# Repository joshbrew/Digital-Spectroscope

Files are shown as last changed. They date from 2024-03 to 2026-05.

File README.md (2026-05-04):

# DIY Digital Spectroscopy

This repository contains free digital spectroscopy software and 3D printable .3mf files (by Davis Fay and Bernard Markus) for an Arducam + 10deg-20deg lens digital spectroscope. Uses stock 1000 line/mm diffraction grating sheets over the lens. We also added a variant (way late, sorry) using the [same tubes](https://www.patonhawksley.com/product-page/benchtop-spectroscope) from the PySpectrometer so you can get a more lab-grade image. The slit uses single edge stainless steel razor blades glued to an adjustible front plate for precise slit width control, we achieved <0.05mm easily with a spacer.

### [Project Review Paper (draft)](https://docs.google.com/document/d/1jqOdnaSaDtLiG4n5NSiPDjHjF8f8xg1o8EnSWcibRvs/edit?usp=drive_link)

## 3D Printing:
- [3D Prints](./3D_PRINTABLE/Main%20Modules/)
- [Arducam Spectrometer Assembly Instructions pdf](./3D_PRINTABLE/Arducam%20Spectrometer%20Assembly%20Instructions.pdf)
- [Smartphone Spectrometer Assembly Instructions pdf](./3D_PRINTABLE/Smartphone%20Spectrometer%20Assembly%20Instructions.pdf)

## Additional Resources
- [Spectrometer Machine Learning Identification Demo](https://github.com/joshbrew/cameraId-wonnx-wasm)
- [Spectrometer Workbench Demo](https://camspectrometer.netlify.app)
- [Py Spectrometer by Les' Lab](https://github.com/leswright1977/PySpectrometer2) - software should work out of the box with the USB camera!
- [Original Theremino DIY Guide](https://www.theremino.com/wp-content/uploads/files/Theremino_Spectrometer_Construction_ENG.pdf)
- [DIY Hyperspectral imaging paper](https://www.mdpi.com/2313-433X/7/8/136)

We are working on a web based hyperspectral imaging tool on top of a proof of concept identification pipeline.

### Revision 2 Phone and Arducam Mounts by Davis Fay:

<table>
  <tr>
    <td>
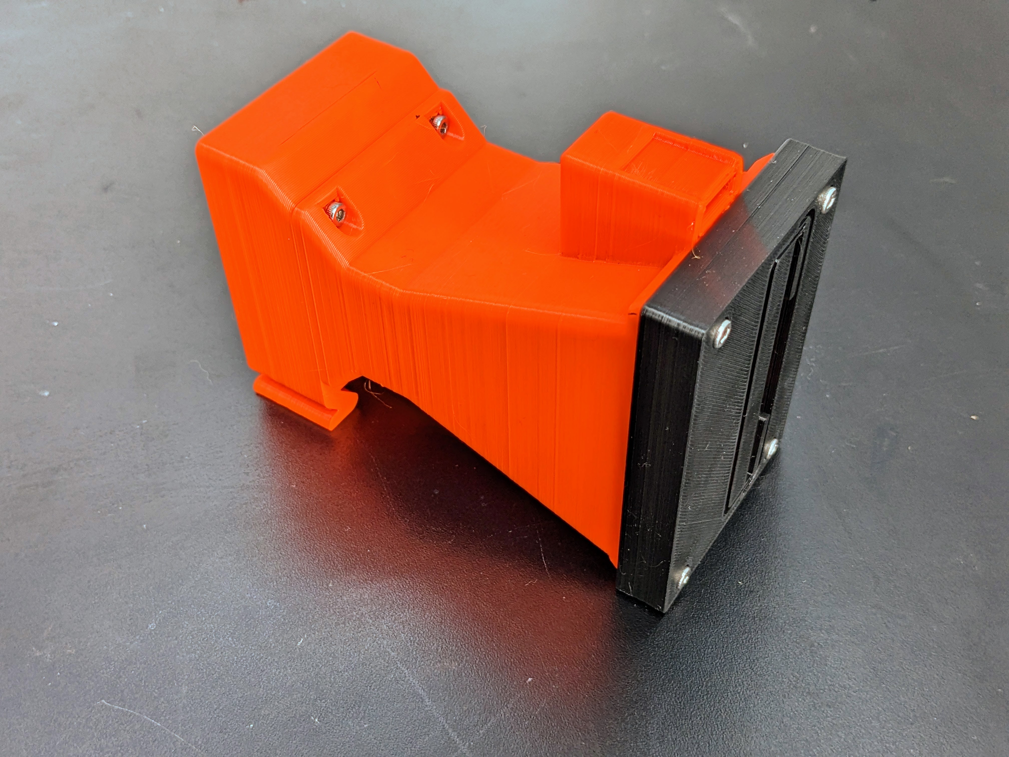
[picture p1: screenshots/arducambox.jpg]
boxa
      
    </td>
    <td>
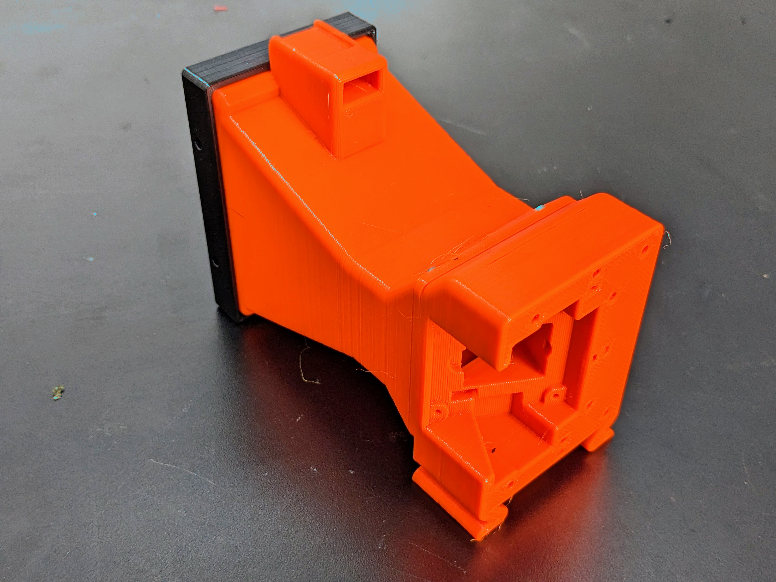
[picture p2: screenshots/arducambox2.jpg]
      
    </td>
  </tr>
  <tr>
    <td>
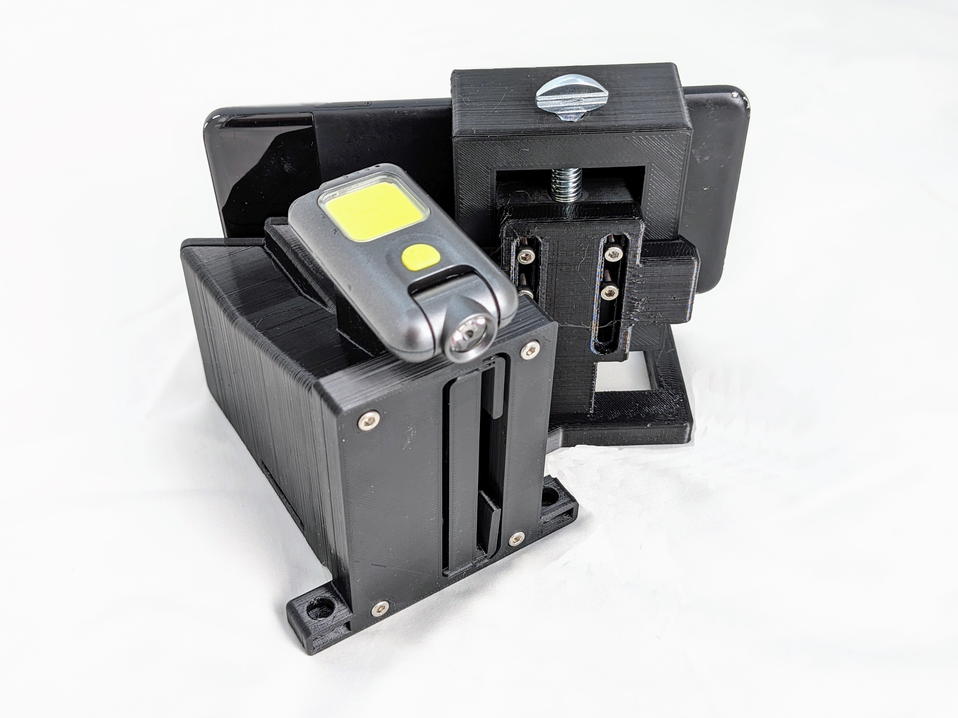
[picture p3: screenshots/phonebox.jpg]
      
    </td>
    <td>
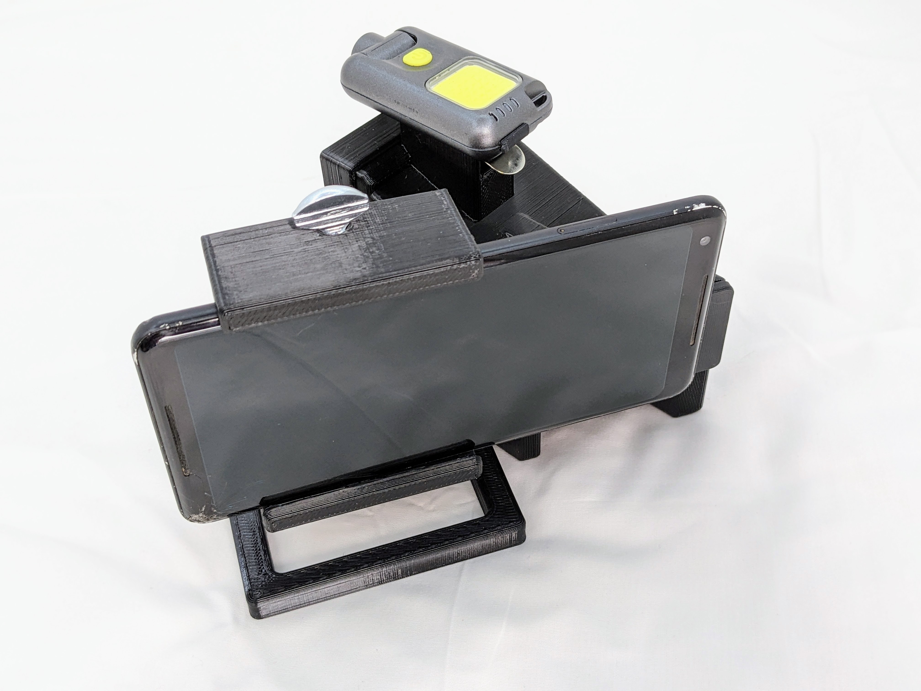
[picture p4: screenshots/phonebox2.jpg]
      
    </td>
  </tr>
</table>

### Phone Hyperspectral Imaging Results:

<table>
  <tr>
    <td>
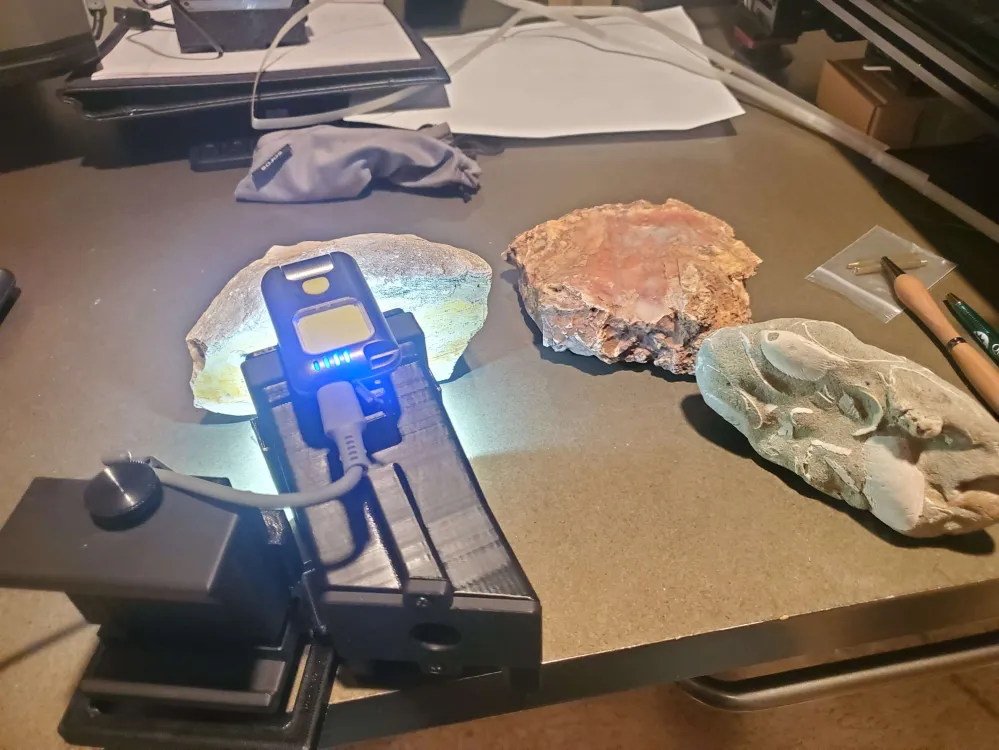
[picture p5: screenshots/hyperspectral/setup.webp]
setup
      
    </td>
    <td>
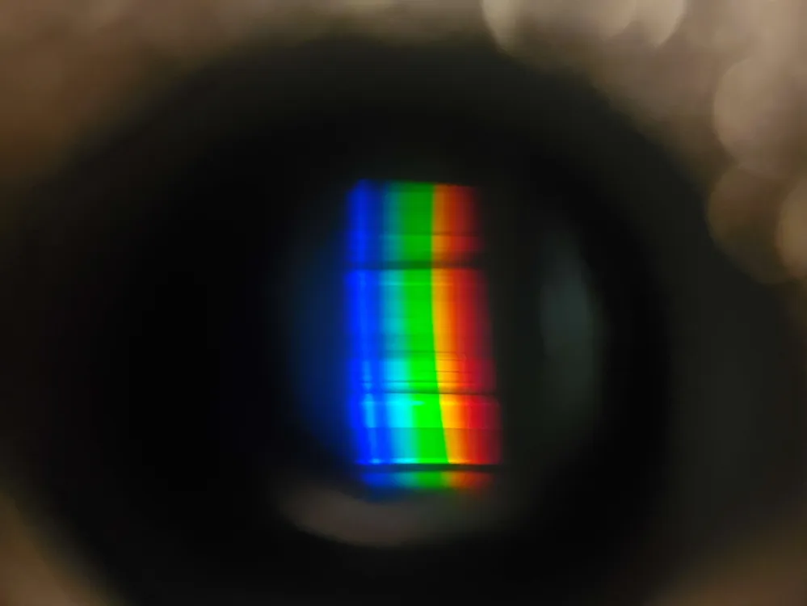
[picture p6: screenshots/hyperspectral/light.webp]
light
      
    </td>
    <td>
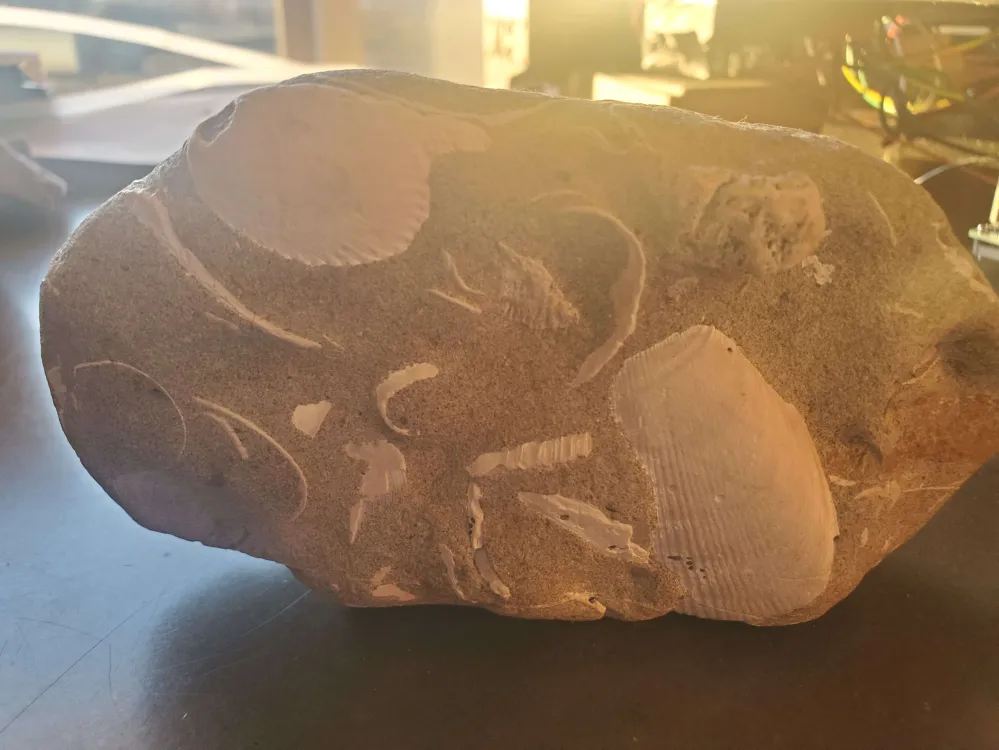
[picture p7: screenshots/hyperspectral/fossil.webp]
fossil
      
    </td>
  </tr>
  <tr>
    <td colSpan="2">
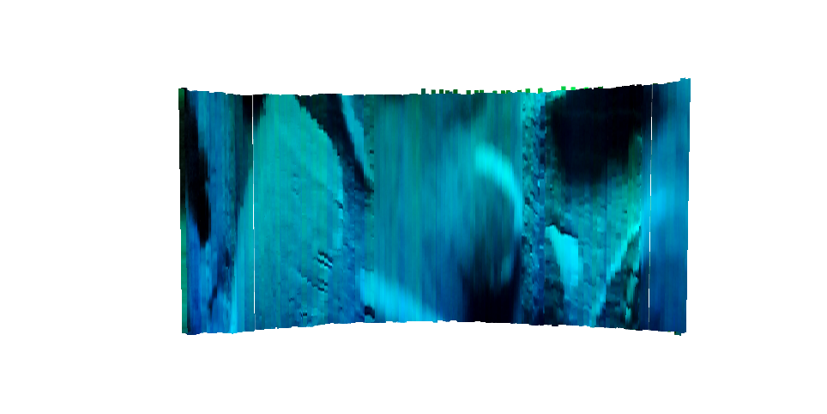
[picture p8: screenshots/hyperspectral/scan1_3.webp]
scan
      
    </td>
    <td>
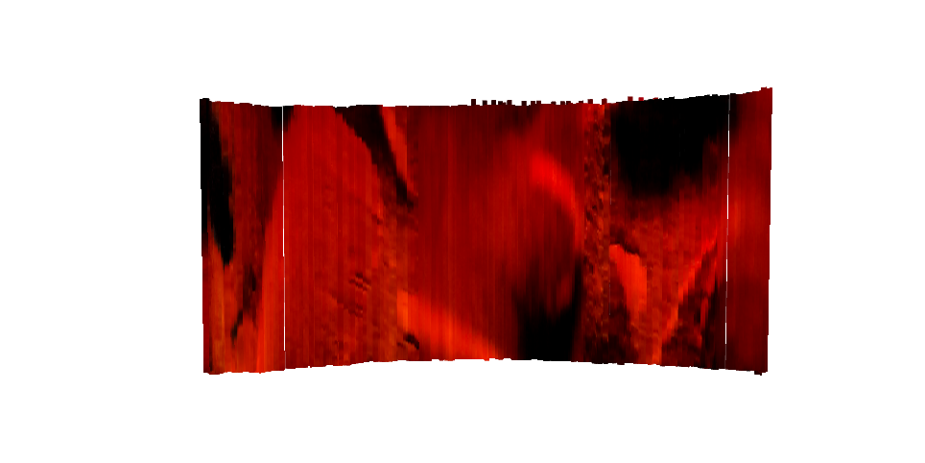
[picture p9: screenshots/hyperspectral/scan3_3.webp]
scan2
      
    </td>
  </tr>
</table>

### Revision 1 by Bernard Markus:

<table>
  <tr>
    <td>
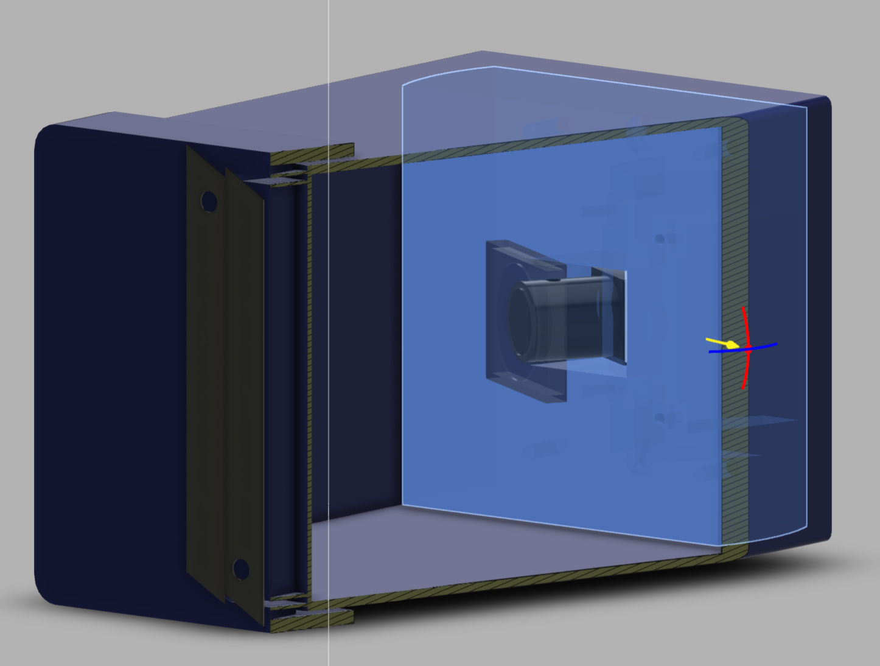
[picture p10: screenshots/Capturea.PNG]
capturea
      
    </td>
    <td>
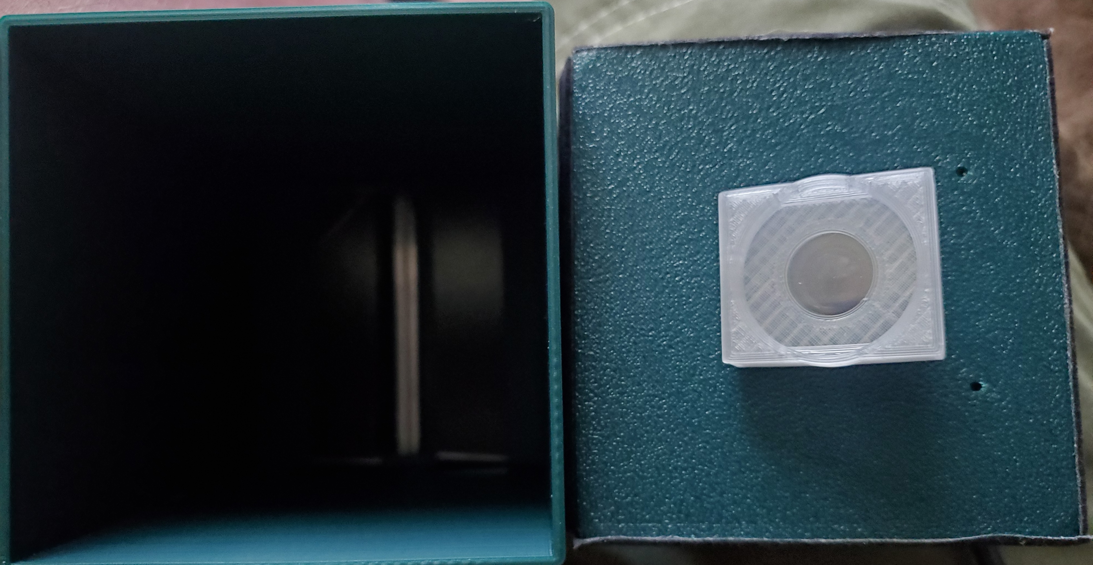
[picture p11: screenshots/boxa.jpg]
      
    </td>
    <td>
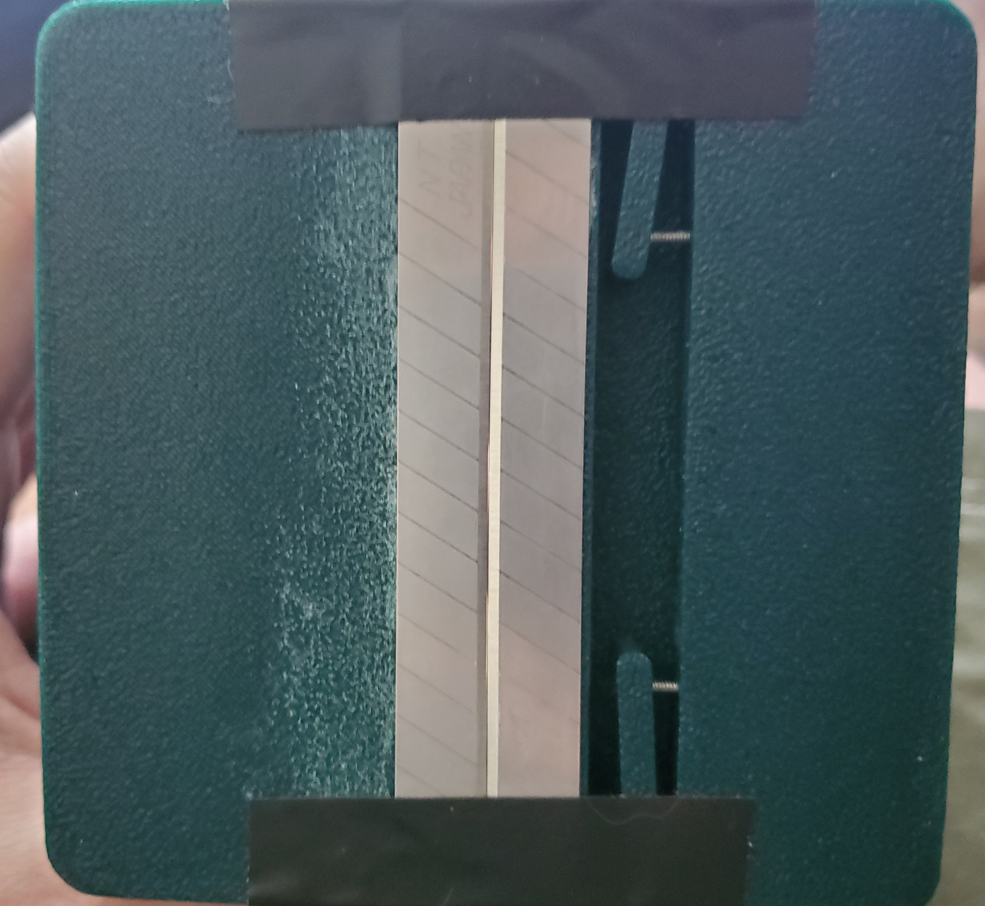
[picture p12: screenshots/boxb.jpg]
boxb
      
    </td>
  </tr>
  <tr>
    <td>
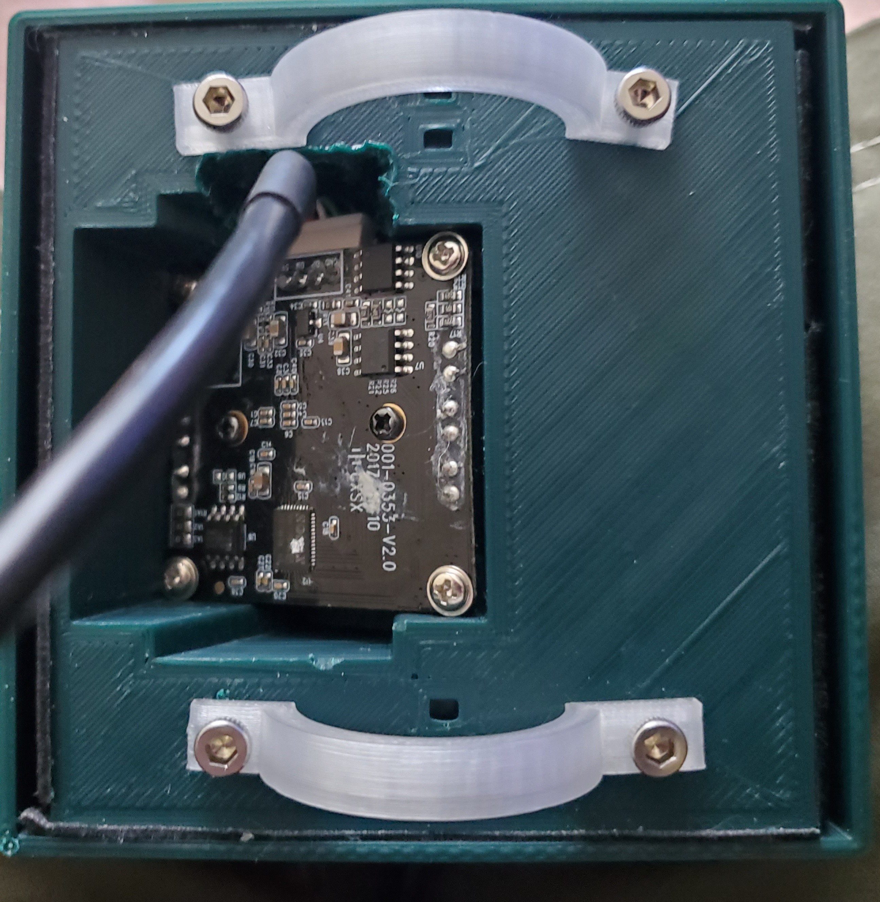
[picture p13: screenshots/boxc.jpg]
boxc
      
    </td>
    <td>
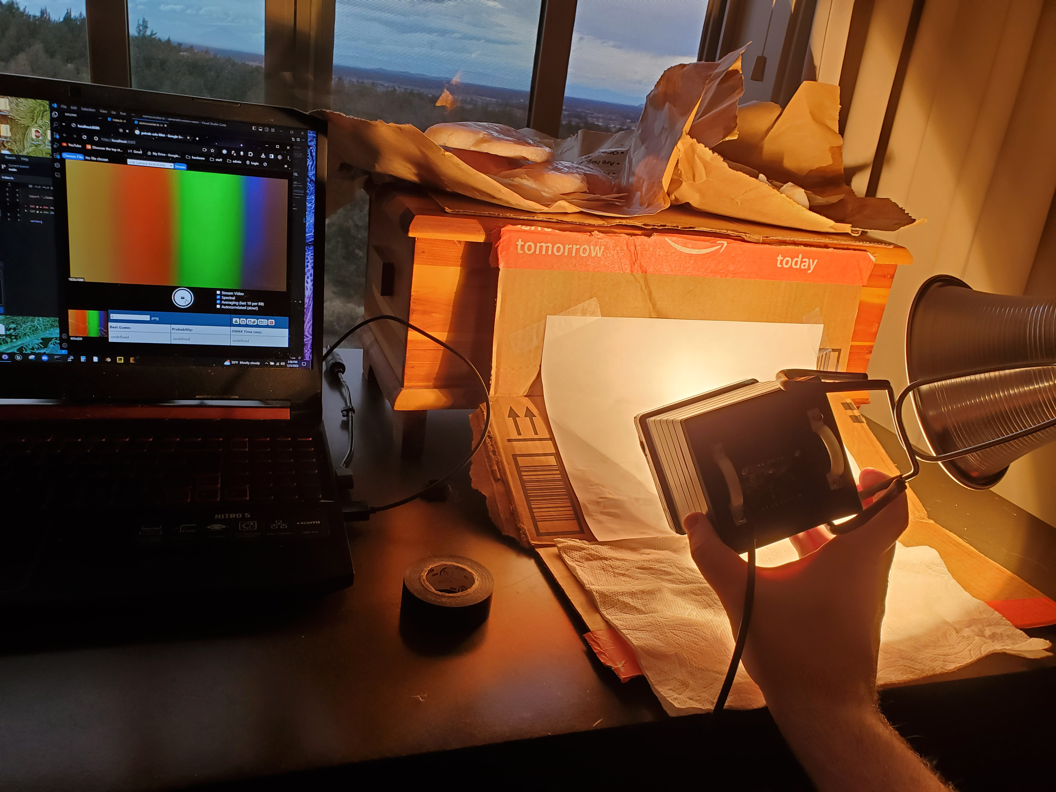
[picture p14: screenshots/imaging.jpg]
      
    </td>
    <td>
      Chocolate bar wrapper hyperspectral scan:<br>
      Capture2
    </td>
  </tr>
</table>

Make sure the diffraction grating is aligned vertically with the slit. The camera rotation should be so that the image is horizontal, you can have it aligned right to left or left to right for increasing wavelength at your preference.

## Software demo

Perform digital spectral decomposition in your browser! 

[ONNX Camera ID Demo](https://github.com/joshbrew/cameraId-wonnx-wasm) for a real time video image classifier demo, which will analyze averaged frames from your digital spectroscope and run results through a classifier or let you generate datasets on the fly. Also links to the training and exporting software for creating compressed XGBoost models from your dataset.

This repo comes with a digital spectrometer workbench prototype, works with any webcam or image/video uploads. This is a pre-alpha functional test. See the live demo at https://camspectrometer.netlify.app built directly from this repo using Netlify.

To run:
`npm start` or `tinybuild`

Or `npm i -g tinybuild` then the above command.

Software example (cropped):
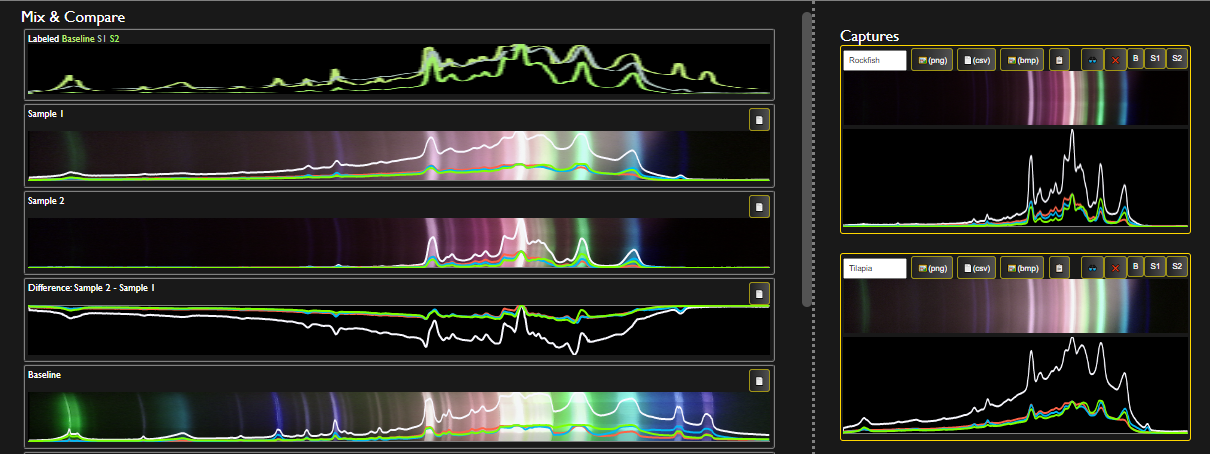
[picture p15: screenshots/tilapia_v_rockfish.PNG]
scrn


My first test of a tabletop spectrometer using a 1080p wifi cam, 1000 line/mm off-the-shelf diffraction grating (e.g. from Amazon), black foam board, and a lot of tape:
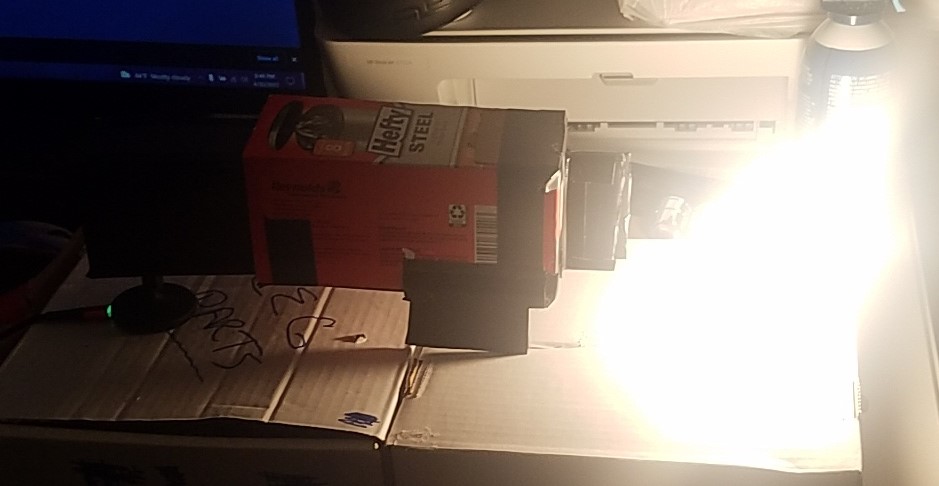
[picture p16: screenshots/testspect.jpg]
test


Results - sunlight through my window:
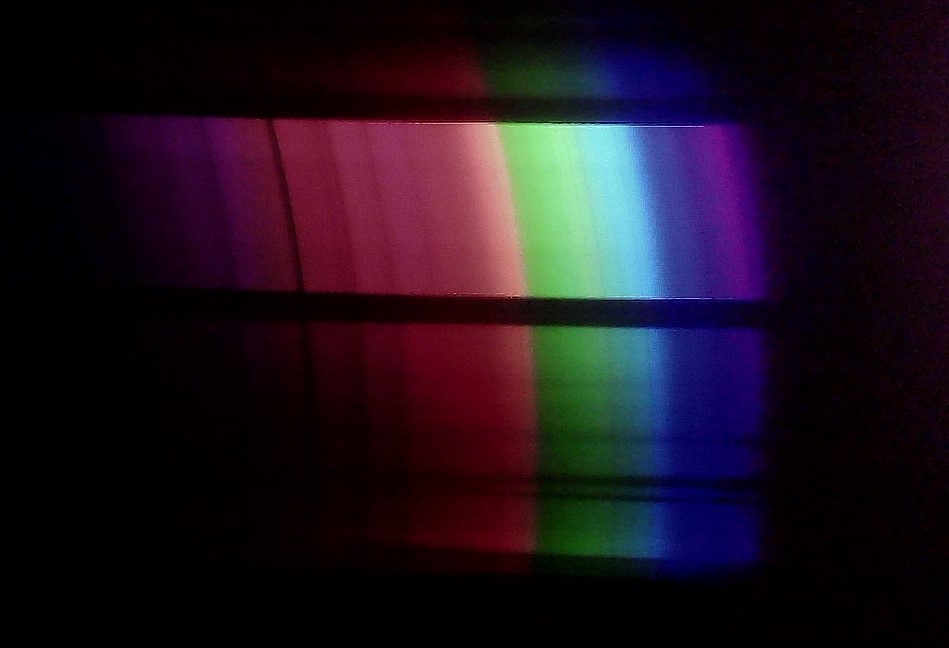
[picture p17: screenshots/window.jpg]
wind


- Not yet added: wavelength estimation, etc. 

All of the prototypes by Bernard:
- [Draft Viewer from Bernard Markus](https://a360.co/3FZsu7q)
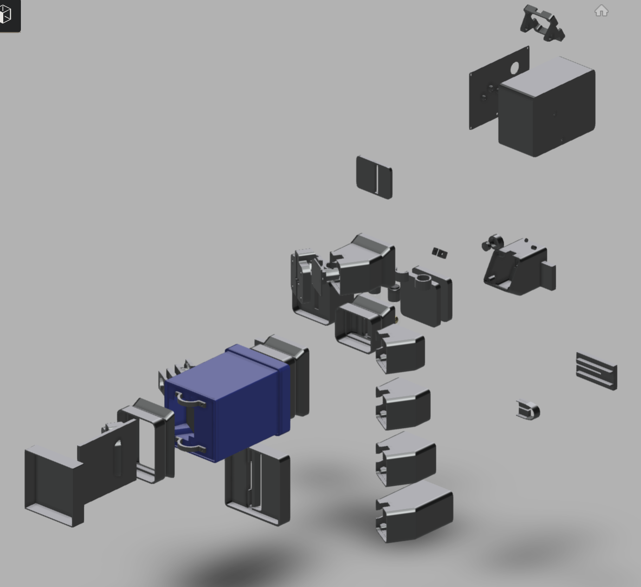
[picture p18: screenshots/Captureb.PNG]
prototypes


### Credits
- 3D print files by Bernard Markus and Davis Fay
- Spectrometer software demo by Joshua Brewster and Garrett Flynn.
- Fishazam project by Yassine Santissi.
- This project is being developed for creating a fish identification dataset. 

Inspired by the [Theremino spectrometer tutorial](https://www.theremino.com/wp-content/uploads/files/Theremino_Spectrometer_Construction_ENG.pdf), with a much needed update using an accessible browser framework. You can use this to build your own.

###### Sponsored by [Schmidt Marine](https://www.schmidtmarine.org/) Foundation.

We recommend using the 1080p Arducam with an 8mm lens with no IR-CUT filter or night vision LEDs (you can just unplug them if they come with it). The diffraction grating is the one from children's toy science kits. The box, well we just used what was within reach... 

We're going to develop our own dedicated low cost solution to help run mass data collection experiments to test fish being sold on the market for quality, correct identification, etc. purposes.

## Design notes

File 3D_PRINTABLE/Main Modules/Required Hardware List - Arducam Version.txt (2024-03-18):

REQUIRED HARDWARE

[Qty. 8] - #4 x 1/2" Stainless Steel Wood Screws, or M3 x 0.5mm, 10mm-long machine screws (https://www.mcmaster.com/91239A115/)
[Qty. 2] - M1.6 x 0.35mm, 12mm-long machine screws (https://www.mcmaster.com/91292A266/)
[Qty. 1] - 1/4" x 20 square nut (flat/low profile) (for tripod/gimbal mount) (https://www.mcmaster.com/94855A247/)

[Qty. 1] - Portable LED flashlight (recommended - https://a.co/d/3tgldf3)
[Qty. 1] - Arducam (OV2710 is OK e.g. https://www.amazon.com/dp/B07CSPB8SD/)
[Qty. 1] - 16mm M12 lens (20 deg) (e.g. https://www.amazon.com/dp/B07VDWNSG9)
[Qty. 4] - Motherboard screws for Arducam (included w/ camera) 
[Qty. 2] - 80mm-100mm snap-off/breakaway blades - (https://www.amazon.com/dp/B0CCRD8HMW)
[Qty. 1] - 1000 line/mm diffraction grating (https://www.amazon.com/dp/B00K6K3MCW/)

PRINT SETTINGS:
- .4mm nozzle is OK, 
- PLA is OK. We prefer [black PLA+](https://www.amazon.com/PLA-Filament-SUNLU-Dimensional-Plus/dp/B08CVG2RVP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) or [black PETG-CF](https://www.amazon.com/Filament-Dimensional-Accuracy-Printing-Polycarbonate/dp/B075SXS6NP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)
- 2 walls OK
- 20% infill OK. Material should not be translucent or highly reflective.
- Use Supports on 90deg overhang for headlamp mount. Not needed anywhere else except maybe the lens caps depending on your printer.

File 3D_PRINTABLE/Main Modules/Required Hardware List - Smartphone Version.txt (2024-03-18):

REQUIRED HARDWARE
Updated 2023-12-14

[Qty. 12] - #4 x 1/2" Stainless Steel Wood Screws, or M3 x 0.5mm, 10mm-long machine screws (https://www.mcmaster.com/91239A115/)
[Qty. 2] - M1.6 x 0.35mm, 12mm-long machine screws (https://www.mcmaster.com/91292A266/)
[Qty. 2] - 1/4" x 20 square nut (flat/low profile) (for tripod/gimbal mount) (https://www.mcmaster.com/94855A247/)
[Qty. 1] - 1/4" x 20 thumbwheel (for phone clamp quick release) (https://www.mcmaster.com/91185A669)
[Qty. 1] - ~1.5" Spring (https://www.mcmaster.com/9434K77/)

[Qty. 1] - Portable LED flashlight (recommended - https://a.co/d/3tgldf3)
[Qty. 2] - 80mm-100mm snap-off/breakaway blades - (https://www.amazon.com/dp/B0CCRD8HMW)
[Qty. 1] - 1000 line/mm diffraction grating (https://www.amazon.com/dp/B00K6K3MCW/)

PRINT SETTINGS:
- .4mm nozzle is OK, 
- PLA is OK. We prefer [black PLA+](https://www.amazon.com/PLA-Filament-SUNLU-Dimensional-Plus/dp/B08CVG2RVP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) or [black PETG-CF](https://www.amazon.com/Filament-Dimensional-Accuracy-Printing-Polycarbonate/dp/B075SXS6NP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)
- 2 walls OK
- 20% infill OK. Material should not be translucent or highly reflective.
- Use Supports on 90deg overhang for headlamp mount. Not needed anywhere else except maybe the lens caps depending on your printer.

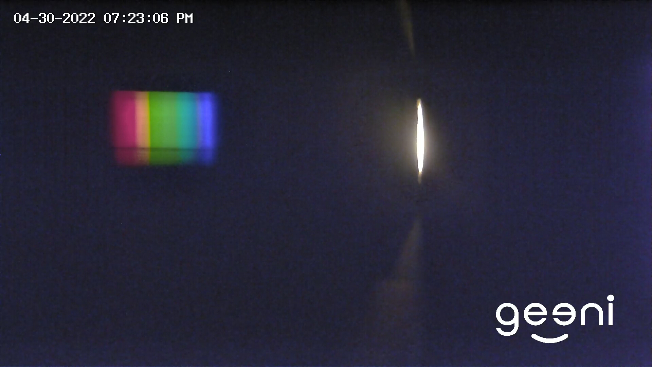
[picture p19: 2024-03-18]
demo_app/src/assets/spectrum2.jpg

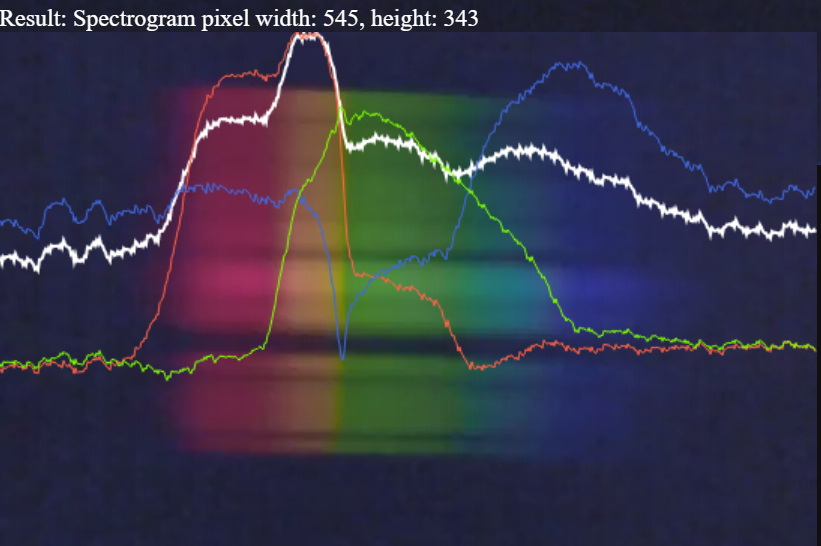
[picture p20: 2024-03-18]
demo_app/src/assets/spectrograms/shrimp.PNG

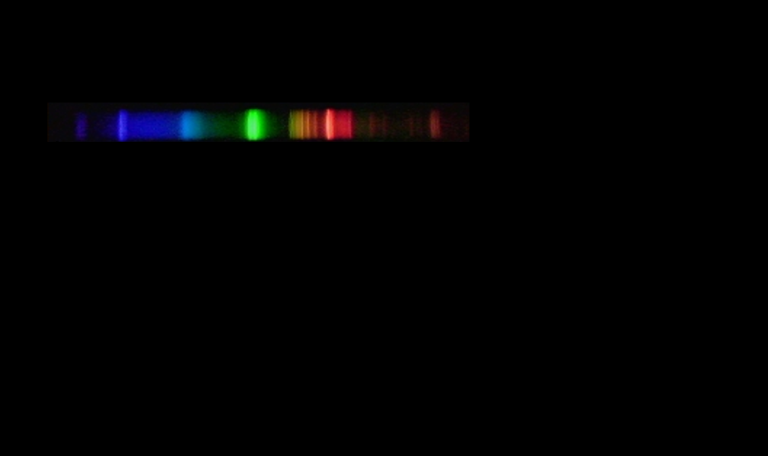
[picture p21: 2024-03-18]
demo_app/src/assets/spectrum_full.png

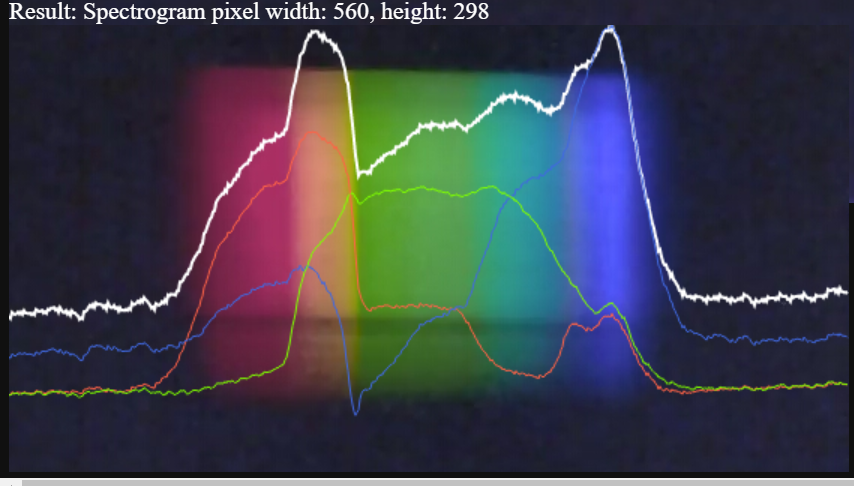
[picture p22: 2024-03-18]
demo_app/src/assets/spectrograms/baseline.PNG

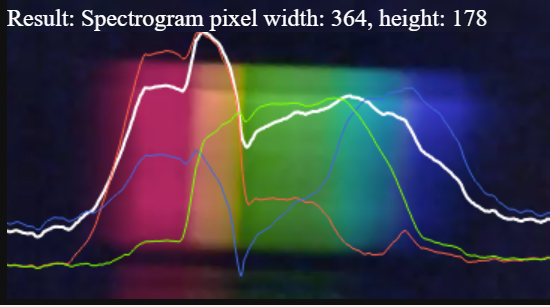
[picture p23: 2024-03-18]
demo_app/src/assets/spectrograms/chickenfatspect.PNG

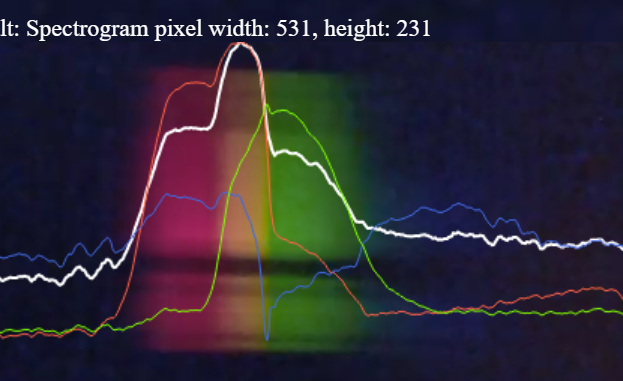
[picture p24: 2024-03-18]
demo_app/src/assets/spectrograms/brownbeerbottle.png

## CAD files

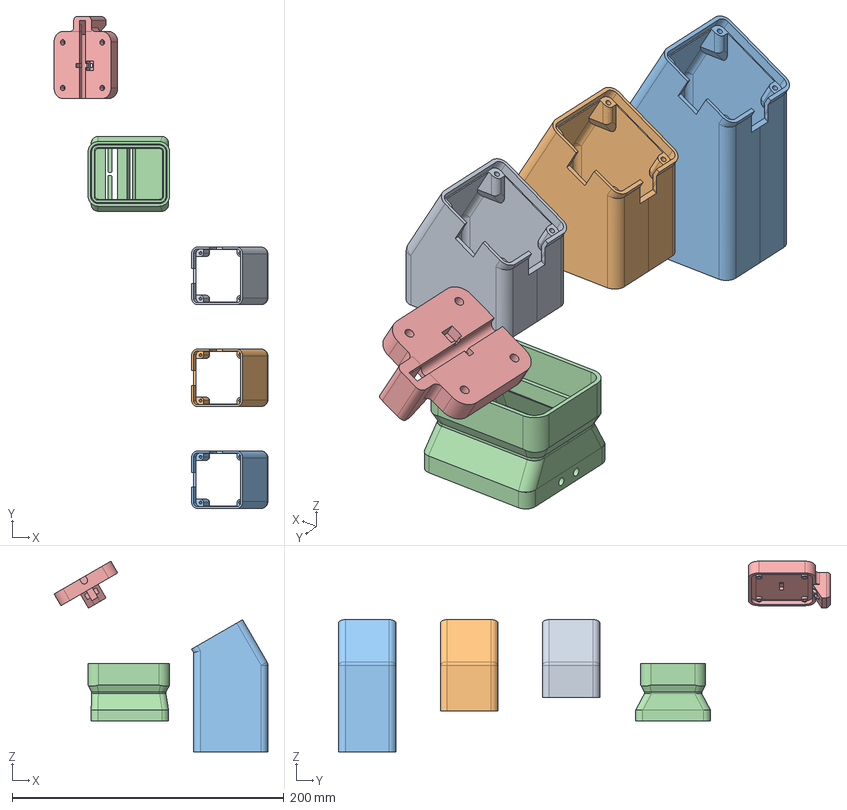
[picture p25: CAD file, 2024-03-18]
3D_PRINTABLE/Drafts/Component16.step
157.3 x 361.9 x 140.3 mm

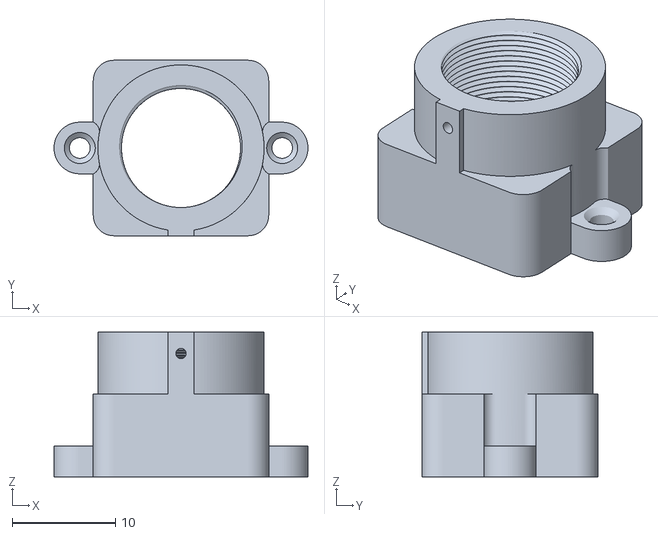
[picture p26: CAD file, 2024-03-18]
3D_PRINTABLE/M12_Mounts/20mm M12 Lens Mount - Beveled.stl
24.6 x 17.0 x 14.0

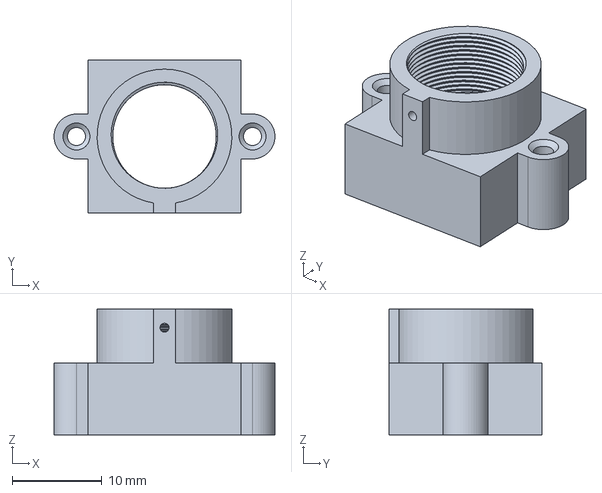
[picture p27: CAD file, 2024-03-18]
3D_PRINTABLE/M12_Mounts/20mm_Mount/M12_Camera_Mount_v2.stp
24.6 x 17.0 x 14.0 mm

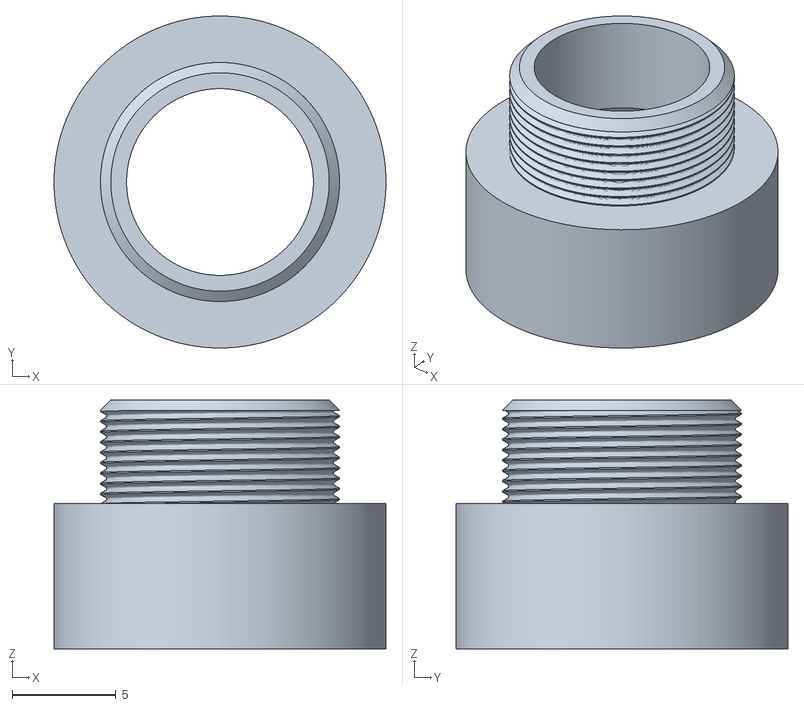
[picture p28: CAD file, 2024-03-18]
3D_PRINTABLE/M12_Mounts/Adapter_Rings/M12m6.stl
16.0 x 16.0 x 12.0

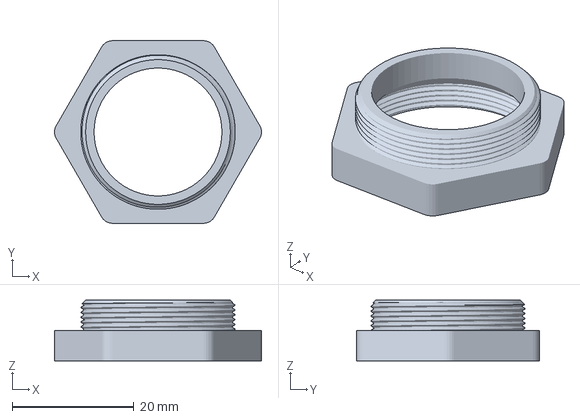
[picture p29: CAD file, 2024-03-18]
3D_PRINTABLE/M12_Mounts/Tubes_and_Rings/5mm_Ring.3mf
34.0 x 30.0 x 10.0 mm

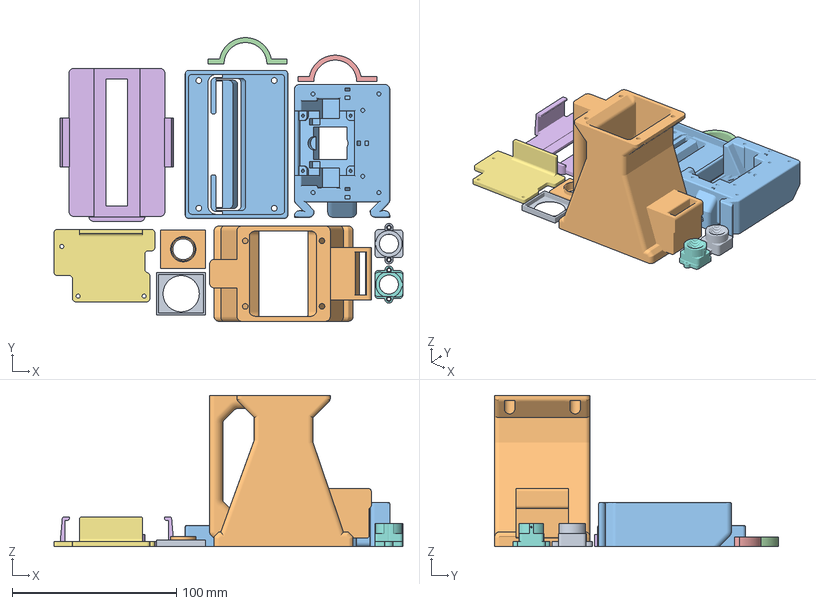
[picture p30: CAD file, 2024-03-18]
3D_PRINTABLE/Main Modules/Arducam_Spectrometer_BambuStudio.3mf
212.2 x 172.5 x 92.0 mm
Arducam_Spectrometer_Revision2.3mf
Arducam_Spectrometer_Revision2.3mf(1)
Arducam_Spectrometer_Revision2.3mf(5)
Arducam_Spectrometer_Box_Simple.3mf(3)
Arducam_Spectrometer_Box_Simple.3mf(4)
Aperture_Cover_Clips.stl
Arducam_Cover.stl
18mm M12 Lens Mount - Beveled.stl
20mm M12 Lens Mount - Beveled.stl
Central_Frame_AC_Wide.stl
Camera_Mount.stl

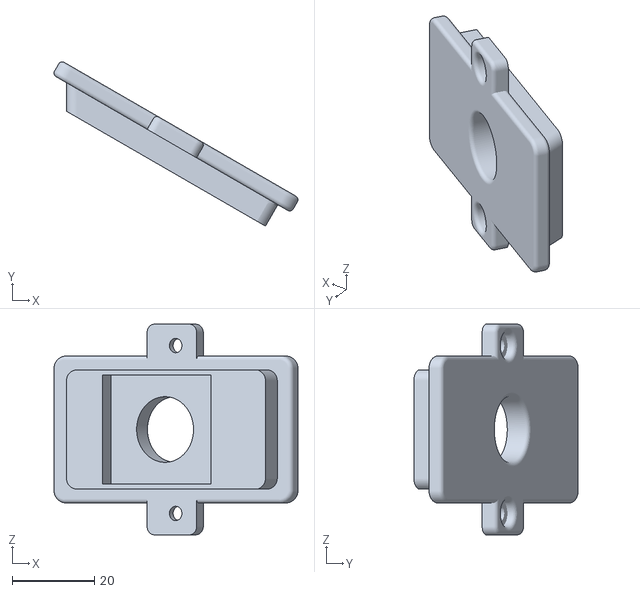
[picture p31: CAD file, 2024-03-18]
3D_PRINTABLE/Main Modules/Smartphone Spectrometer 3D Printed Parts/Diffraction_Cap.stl
59.2 x 39.9 x 51.1

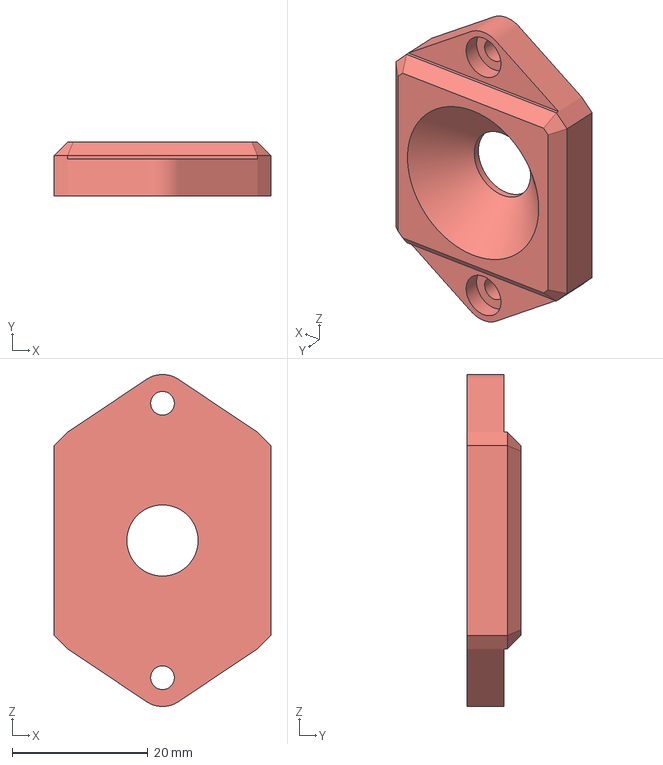
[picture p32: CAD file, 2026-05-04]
3D_PRINTABLE/PhoneMiniSpectrometer/lensCover1.3mf
32.0 x 8.00 x 49.0 mm

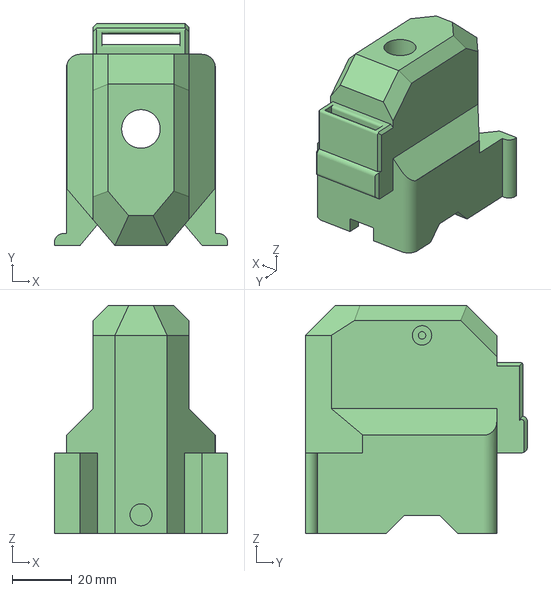
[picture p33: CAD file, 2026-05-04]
3D_PRINTABLE/PocketVersion/Pocket Spectrometer Frame Short.3mf
58.0 x 74.3 x 76.3 mm

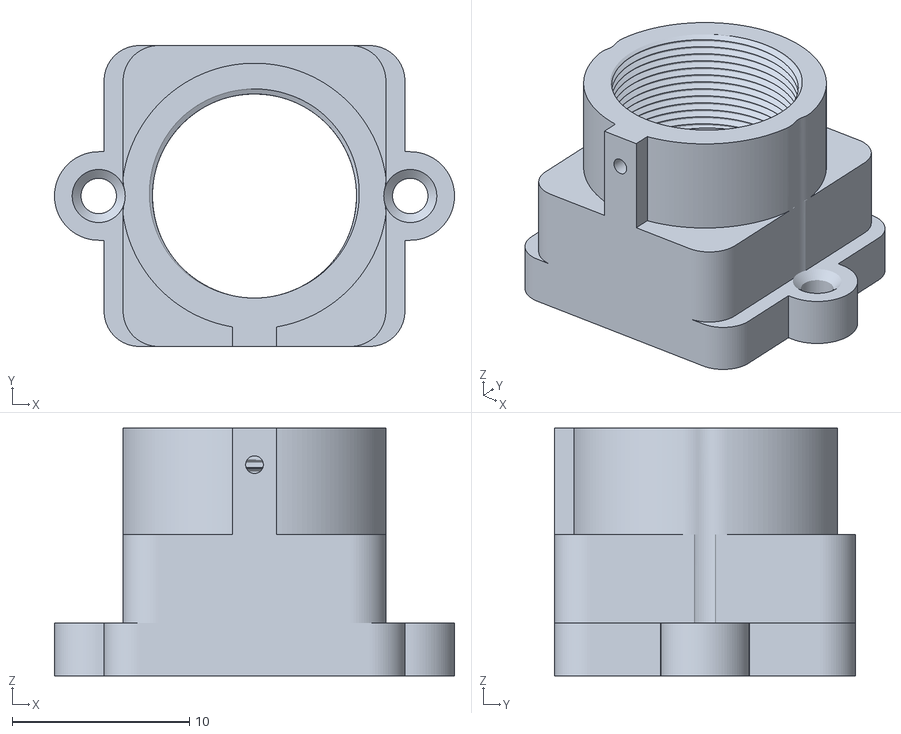
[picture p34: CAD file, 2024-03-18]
3D_PRINTABLE/M12_Mounts/20mm M12 Lens Holder.stl
22.6 x 17.0 x 14.0

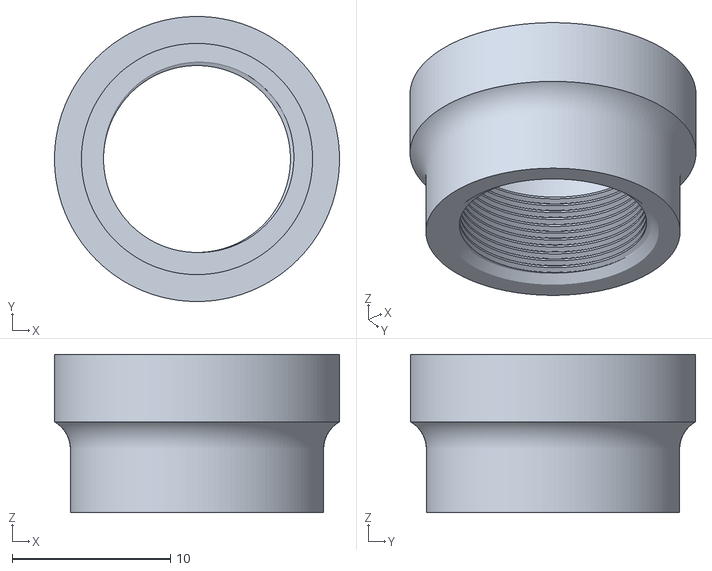
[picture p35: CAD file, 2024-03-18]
3D_PRINTABLE/M12_Mounts/Adapter_Rings/m12casquillo_-_Part_1.stl
18.0 x 18.0 x 10.0

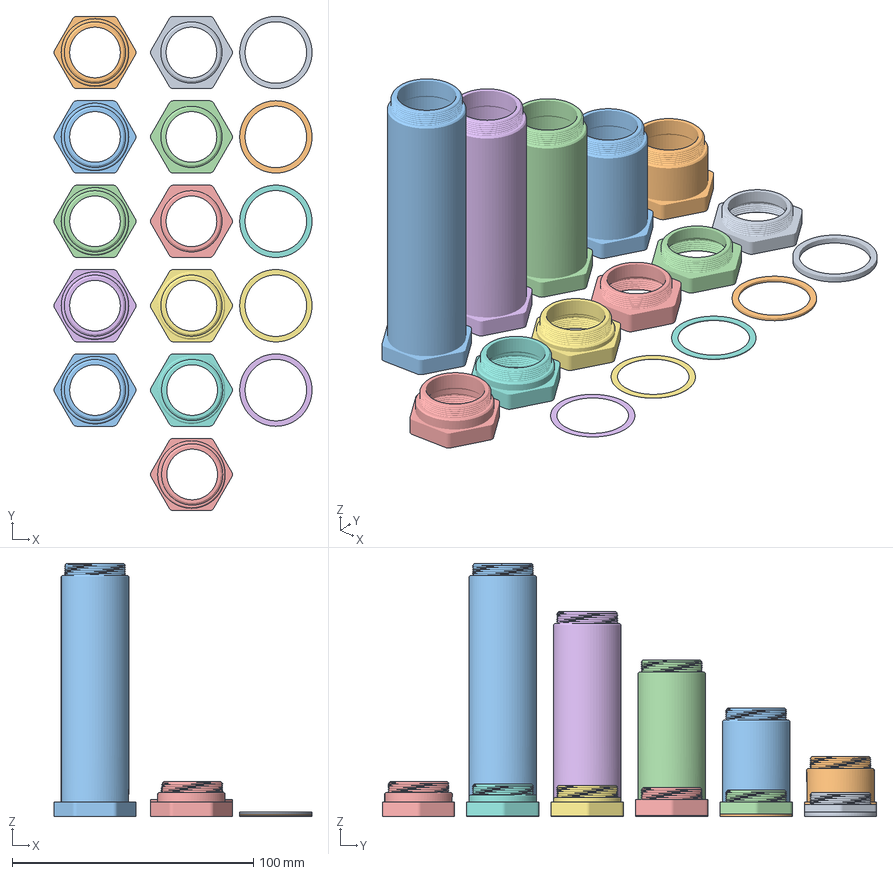
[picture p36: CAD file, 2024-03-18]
3D_PRINTABLE/M12_Mounts/Tubes_and_Rings/C-Mount_tube_ring v24.3mf
107.0 x 205.0 x 105.0 mm
C-Mount_tube_ring v24.3mf(9)
C-Mount_tube_ring v24.3mf(7)
C-Mount_tube_ring v24.3mf(8)
C-Mount_tube_ring v24.3mf(10)
C-Mount_tube_ring v24.3mf(6)
C-Mount_tube_ring v24.3mf
C-Mount_tube_ring v24.3mf(1)
C-Mount_tube_ring v24.3mf(2)
C-Mount_tube_ring v24.3mf(4)
C-Mount_tube_ring v24.3mf(3)
C-Mount_tube_ring v24.3mf(5)
C-Mount_tube_ring v24.3mf(11)
C-Mount_tube_ring v24.3mf(12)
C-Mount_tube_ring v24.3mf(13)
C-Mount_tube_ring v24.3mf(14)
C-Mount_tube_ring v24.3mf(15)

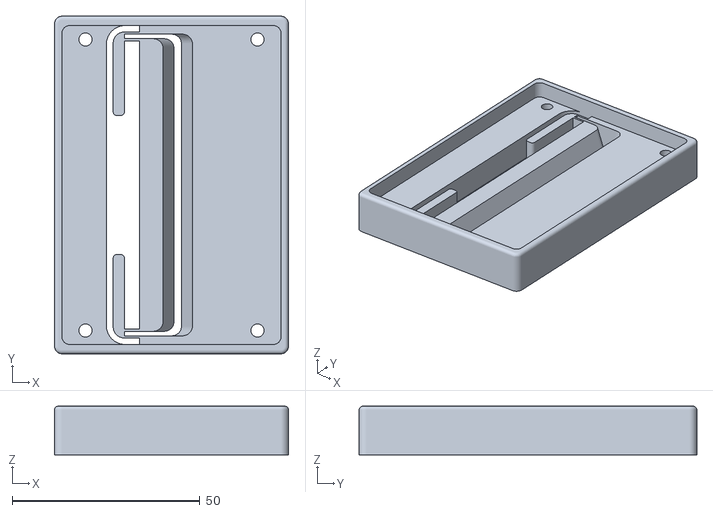
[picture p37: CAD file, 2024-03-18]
3D_PRINTABLE/Main Modules/Arducam Spectrometer 3D Printed Parts/Aperture_Cap.stl
62.4 x 90.0 x 13.0

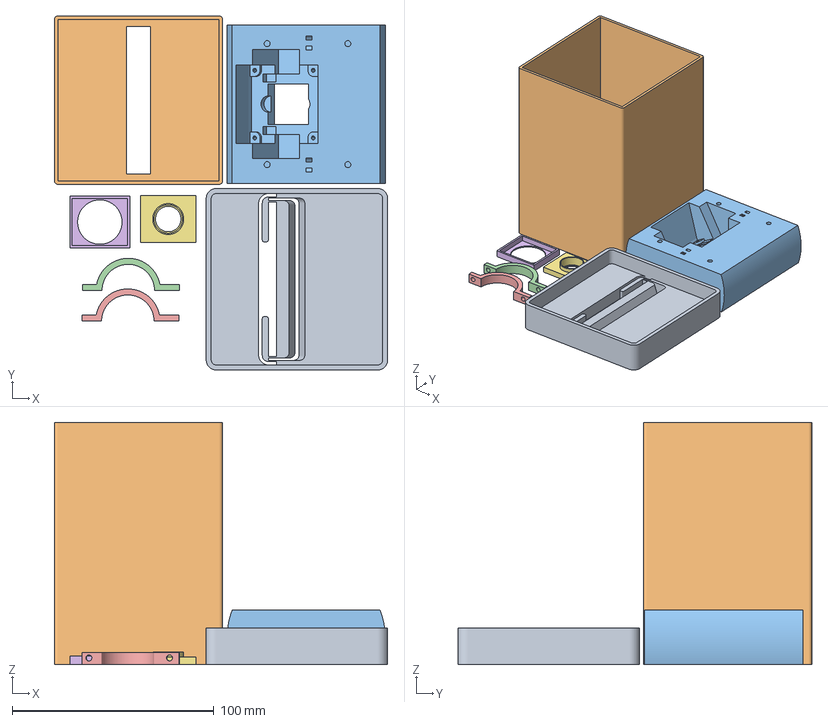
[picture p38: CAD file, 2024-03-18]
3D_PRINTABLE/Main Modules/Arducam_Spectrometer_Box_Simple.3mf
165.3 x 175.5 x 120.0 mm
Arducam_Spectrometer_Box_Simple.3mf
Arducam_Spectrometer_Box_Simple.3mf(1)
Arducam_Spectrometer_Box_Simple.3mf(2)
Arducam_Spectrometer_Box_Simple.3mf(3)
Arducam_Spectrometer_Box_Simple.3mf(4)
Arducam_Spectrometer_Box_Simple.3mf(5)
Arducam_Spectrometer_Box_Simple.3mf(6)

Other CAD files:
3D_PRINTABLE/M12_Mounts/20mm_Mount/M12_Camera_Mount.stl
3D_PRINTABLE/Main Modules/Smartphone Spectrometer 3D Printed Parts/Phone_Clamp_Top.stl
3D_PRINTABLE/PhoneMiniSpectrometer/pocketTubeMount.3mf
3D_PRINTABLE/Drafts/Component16.3mf
3D_PRINTABLE/M12_Mounts/18mm M12 Lens Holder.stl
3D_PRINTABLE/M12_Mounts/18mm M12 Lens Mount - Beveled.stl
3D_PRINTABLE/M12_Mounts/20mm_Mount/M12_Camera_Mount_v2.f3d
3D_PRINTABLE/M12_Mounts/20mm_Mount/M12_Camera_Mount_v2.igs
3D_PRINTABLE/M12_Mounts/Adapter_Rings/M12m5_-_Part_1.stl
3D_PRINTABLE/M12_Mounts/Adapter_Rings/m12casquillo2_1.stl
3D_PRINTABLE/Main Modules/Arducam Spectrometer 3D Printed Parts/Aperture_Cover.stl
3D_PRINTABLE/Main Modules/Arducam Spectrometer 3D Printed Parts/Camera_Cover.stl
3D_PRINTABLE/Main Modules/Arducam Spectrometer 3D Printed Parts/Camera_Mount.stl
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

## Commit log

2024-03-18 clean commit
    [18mm M12 Lens Holder.stl, 18mm M12 Lens Mount - Beveled.stl, 20mm M12 Lens Holder.stl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]
2026-05-04 added mini spectrometer variant (same glass from PySpectrometer)
    [Pocket Spectrometer Frame Short.3mf, PySpectrometer 2 Benchtop Spectrometer Frame Rev 1.3mf, PySpectrometer 2 Pocket Spectrometer Frame Rev 1.3mf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]
